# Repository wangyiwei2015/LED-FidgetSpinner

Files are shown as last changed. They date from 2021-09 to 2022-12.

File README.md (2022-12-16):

# LED-FidgetSpinner
Battery-powered LED Fidget Spinner. **PhOVS**

Design & concept reference: [8Mode Fidget Spinner](https://www.8mode.com/spinner/)

Warning: this is still under development.

Warning: there maybe better MCU model for this application.

### Development Tools

PCB: **KiCAD**

    --> ./FidgetSpinner-PCB/

Firmware: **STM32CubeMX** & **CLion**

    --> ./FidgetSpinner-FW/STM32L010_CLion/

3D Models: **Shapr3D** for iPad

    --> ./FidgetSpinner-Struct/

### BOM

| Name | Model | Package | Quantity | Price (CNY each) |
| --- | --- | --- | --- | --- |
| MCU | STM32L010K8T6 | | 1 | 33 |
| Regulator | BL8530 | | 1 | 0.16 |
| Optical Sensor | GP2S60 | | 1 | 3.50 |
| Switch | MSK-12C02 | | 1 | 0.16 |
| Button | | | 1 | |
| Battery | CR2450 | CR2450  | 3 | |
| Battery Case | | | 3 | |
| LED | warm-white | 0805 | 8 | |
| Diode | D | 0805 | 2 | 0.06 |
| L | 47uH | 0805 | 1 | |
| C | 100nF | 0805 | 3 | |
| C | 1uF | 0805 | 1 | |
| C | 47uF | 0805 | 1 | |
| R_LED | 1k1 | 0805 | 8 | |
| R_IR | 3k3 | 0805 | 1 | |
| R_Comp | 20k | 0805 | 1 | |
| R_Comp | 33k | 0805 | 1 | |
| R_Tr | 1M | 0805 | 1 | |
| R | 10k | 0805 | 3 | |

Different coin-sized 3V battery cells

| Name | Capacity(mAh) | I(uA) | Ic(mA) | Imax(mA) | Weight(g) |
| --- | --- | ----- | --- | --- | --- |
| CR2477 | 950 | 200 | 3 | 20 | 9.9 |
| CR2450 | 550 | 200 | 3 | 20 | 5.8 |
| CR2430 | 270 | 200 | 3 | 20 | 4.3 |
| CR3032 | 550 | 200 | 3 | 20 | 6.8 |
| CR2032 | 210 | 200 | 2 | 20 | 3.0 |
| CR2025 | 150 | 200 | 2 | 20 | 2.5 |

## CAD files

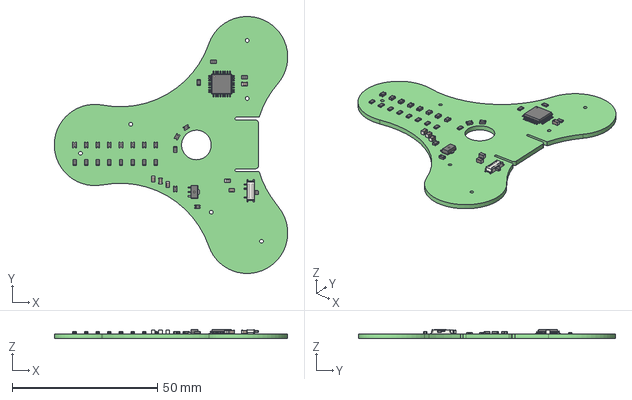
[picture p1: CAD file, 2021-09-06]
FidgetSpinner-PCB/FidgetSpinner.step
80.5 x 88.6 x 3.17 mm

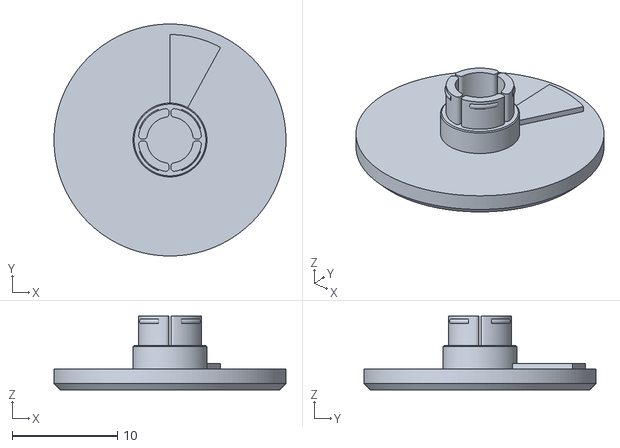
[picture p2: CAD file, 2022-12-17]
FidgetSpinner-Struct/PCap_v3.0-f.stl
22.0 x 22.0 x 7.00

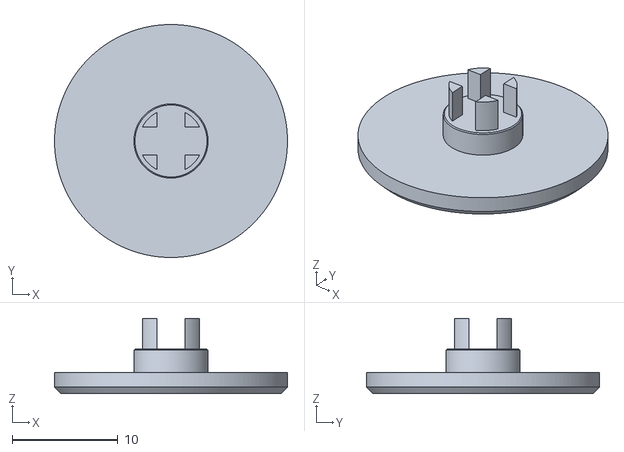
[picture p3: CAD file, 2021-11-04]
FidgetSpinner-Struct/PCap_v2.1.stl
22.0 x 22.0 x 7.10

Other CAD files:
FidgetSpinner-Struct/PCap_v3.0-b.stl

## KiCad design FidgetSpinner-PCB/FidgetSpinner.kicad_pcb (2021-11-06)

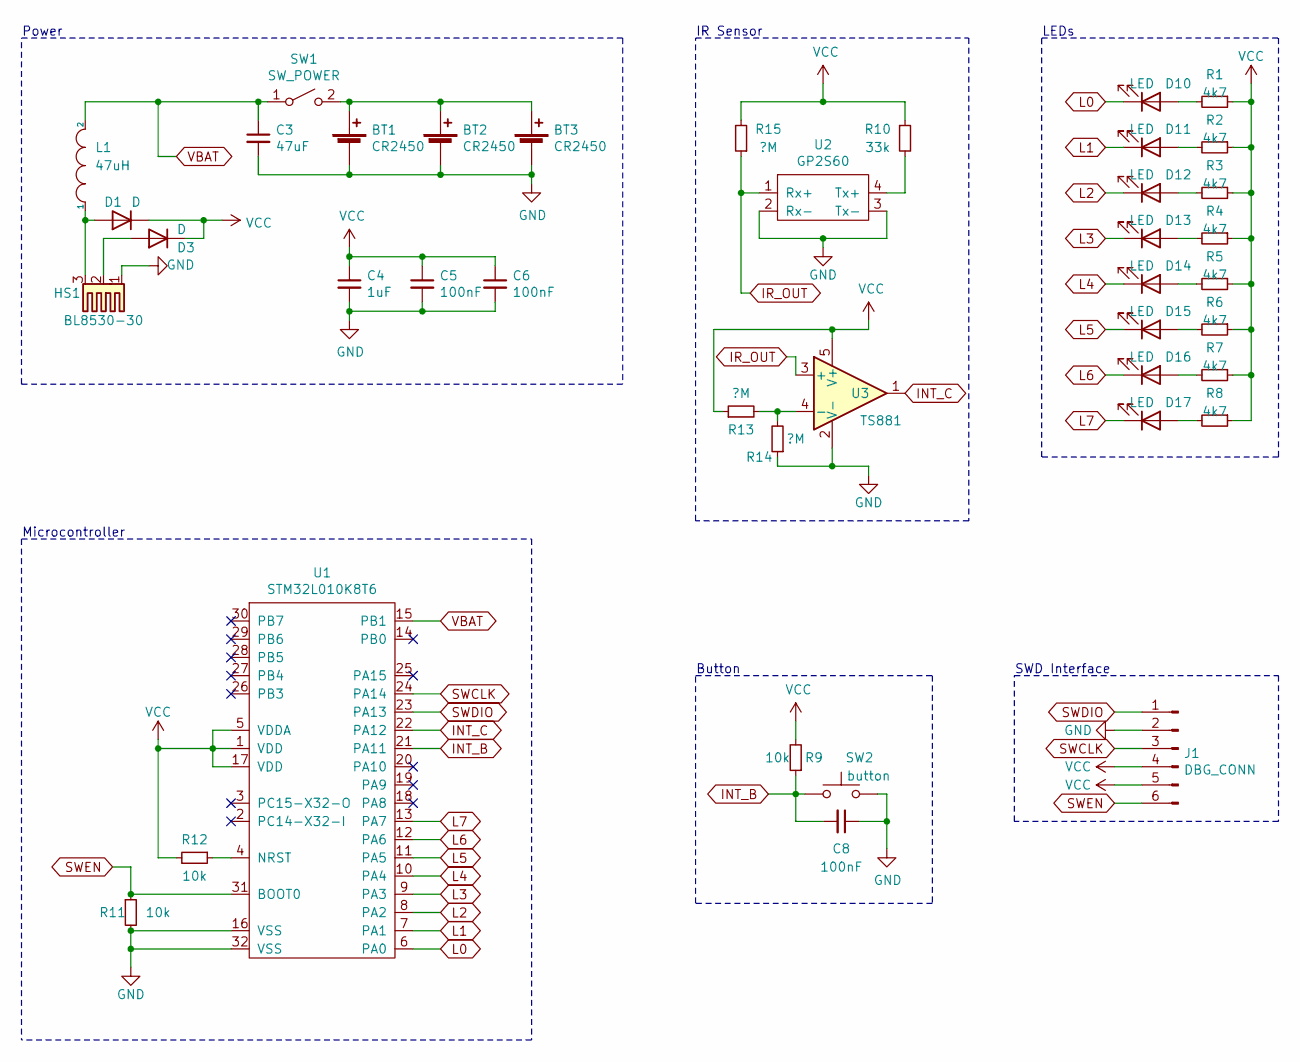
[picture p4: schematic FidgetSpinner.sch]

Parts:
BT1, BT2, BT3: CR2450; BatteryHolder_Keystone_3009_1x2450
C3: 47uF; C_0805_2012Metric_Pad1.18x1.45mm_HandSolder
C4: 1uF; C_0805_2012Metric_Pad1.18x1.45mm_HandSolder
C5, C6, C8: 100nF; C_0805_2012Metric_Pad1.18x1.45mm_HandSolder
D1, D3: D; D_0805_2012Metric_Pad1.15x1.40mm_HandSolder
D10, D11, D12, D13, D14, D15, D16, D17: LED; D_0805_2012Metric_Pad1.15x1.40mm_HandSolder
HS1: BL8530-30; SOT-89-3_Handsoldering
J1: DBG_CONN; PinHeader_1x06_P2.54mm_Horizontal
L1: 47uH; L_0805_2012Metric_Pad1.15x1.40mm_HandSolder
R1, R2, R3, R4, R5, R6, R7, R8: 4k7; R_0805_2012Metric_Pad1.20x1.40mm_HandSolder
R9, R11, R12: 10k; R_0805_2012Metric_Pad1.20x1.40mm_HandSolder
R10: 33k; R_0805_2012Metric_Pad1.20x1.40mm_HandSolder
R13, R14, R15: ?M; R_0805_2012Metric_Pad1.20x1.40mm_HandSolder
SW1: SW_POWER; SW_SPDT_PCM12
SW2: button; SW_SPST_SKQG_WithStem
U1: STM32L010K8T6; LQFP-32_7x7mm_P0.8mm
U2: GP2S60; GP2S60_3217
U3: TS881; SOT-353_SC-70-5

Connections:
GND: BT1.2 (-), BT2.2 (-), BT3.2 (-), C3.2, C4.2, C5.2, C6.2, C8.1, HS1.1, J1.2, R11.2, R14.1, SW2.2, U1.16 (VSS), U1.32 (VSS), U2.2 (Rx-), U2.3 (Tx-), U3.2 (V-); also elsewhere on the board
INT_B: C8.2, R9.1, SW2.1, U1.21 (PA11)
INT_C: U1.22 (PA12), U3.1; also elsewhere on the board
IR_OUT: R15.1, U2.1 (Rx+), U3.3 (+); also elsewhere on the board
L0: D10.1 (K), U1.6 (PA0)
L1: D11.1 (K), U1.7 (PA1)
L2: D12.1 (K), U1.8 (PA2)
L3: D13.1 (K), U1.9 (PA3)
L4: D14.1 (K), U1.10 (PA4)
L5: D15.1 (K), U1.11 (PA5)
L6: D16.1 (K), U1.12 (PA6)
L7: D17.1 (K), U1.13 (PA7)
unnamed: BT1.1 (+), BT2.1 (+), BT3.1 (+), SW1.2 (B)
unnamed: D1.2 (A), HS1.3, L1.1
unnamed: D3.2 (A), HS1.2
unnamed: D10.2 (A), R1.2
unnamed: D11.2 (A), R2.2
unnamed: D12.2 (A), R3.2
unnamed: D13.2 (A), R4.2
unnamed: D14.2 (A), R5.2
unnamed: D15.2 (A), R6.2
unnamed: D16.2 (A), R7.2
unnamed: D17.2 (A), R8.2
unnamed: R10.2, U2.4 (Tx+)
unnamed: R12.1, U1.4 (NRST)
unnamed 25: R13.2, R14.2, U3.4 (-); also elsewhere on the board
SWCLK: J1.3, U1.24 (PA14)
SWDIO: J1.1, U1.23 (PA13)
SWEN: J1.6, R11.1, U1.31 (BOOT0)
VBAT: C3.1, L1.2, SW1.1 (A), U1.15 (PB1)
VCC: C4.1, C5.1, C6.1, D1.1 (K), D3.1 (K), J1.4, J1.5, R1.1, R2.1, R3.1, R4.1, R5.1, R6.1, R7.1, R8.1, R9.2, R10.1, R12.2, R13.1, R15.2, U1.1 (VDD), U1.5 (VDDA), U1.17 (VDD), U3.5 (V+); also elsewhere on the board

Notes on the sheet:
Power
SWD Interface
Button
IR Sensor
LEDs
Microcontroller

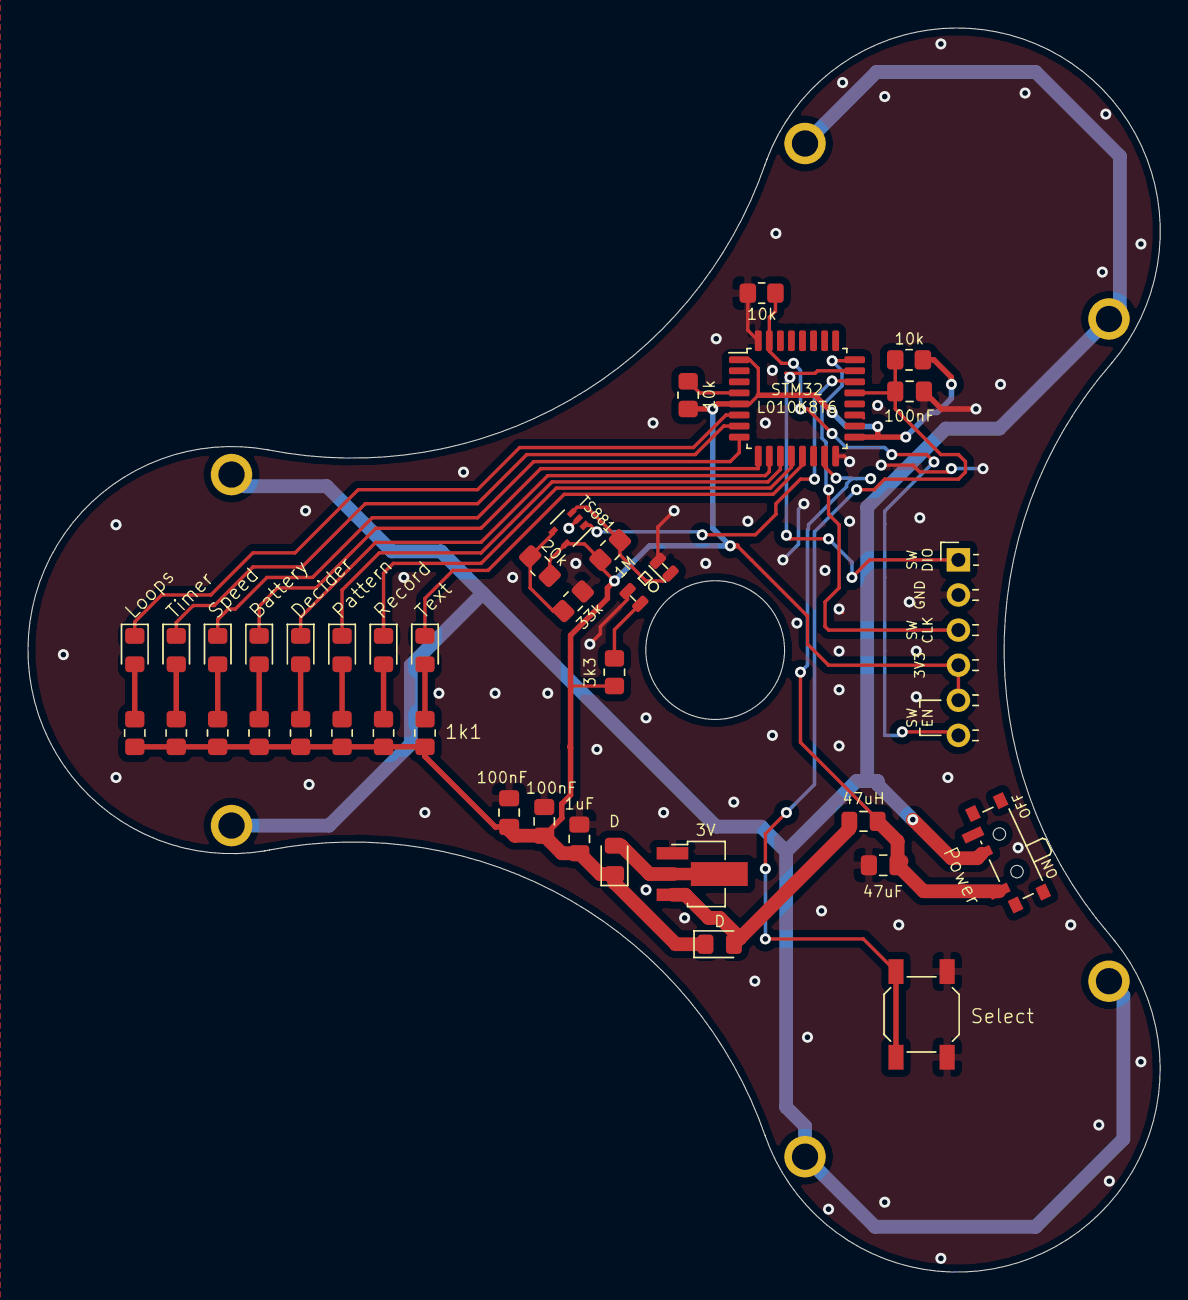
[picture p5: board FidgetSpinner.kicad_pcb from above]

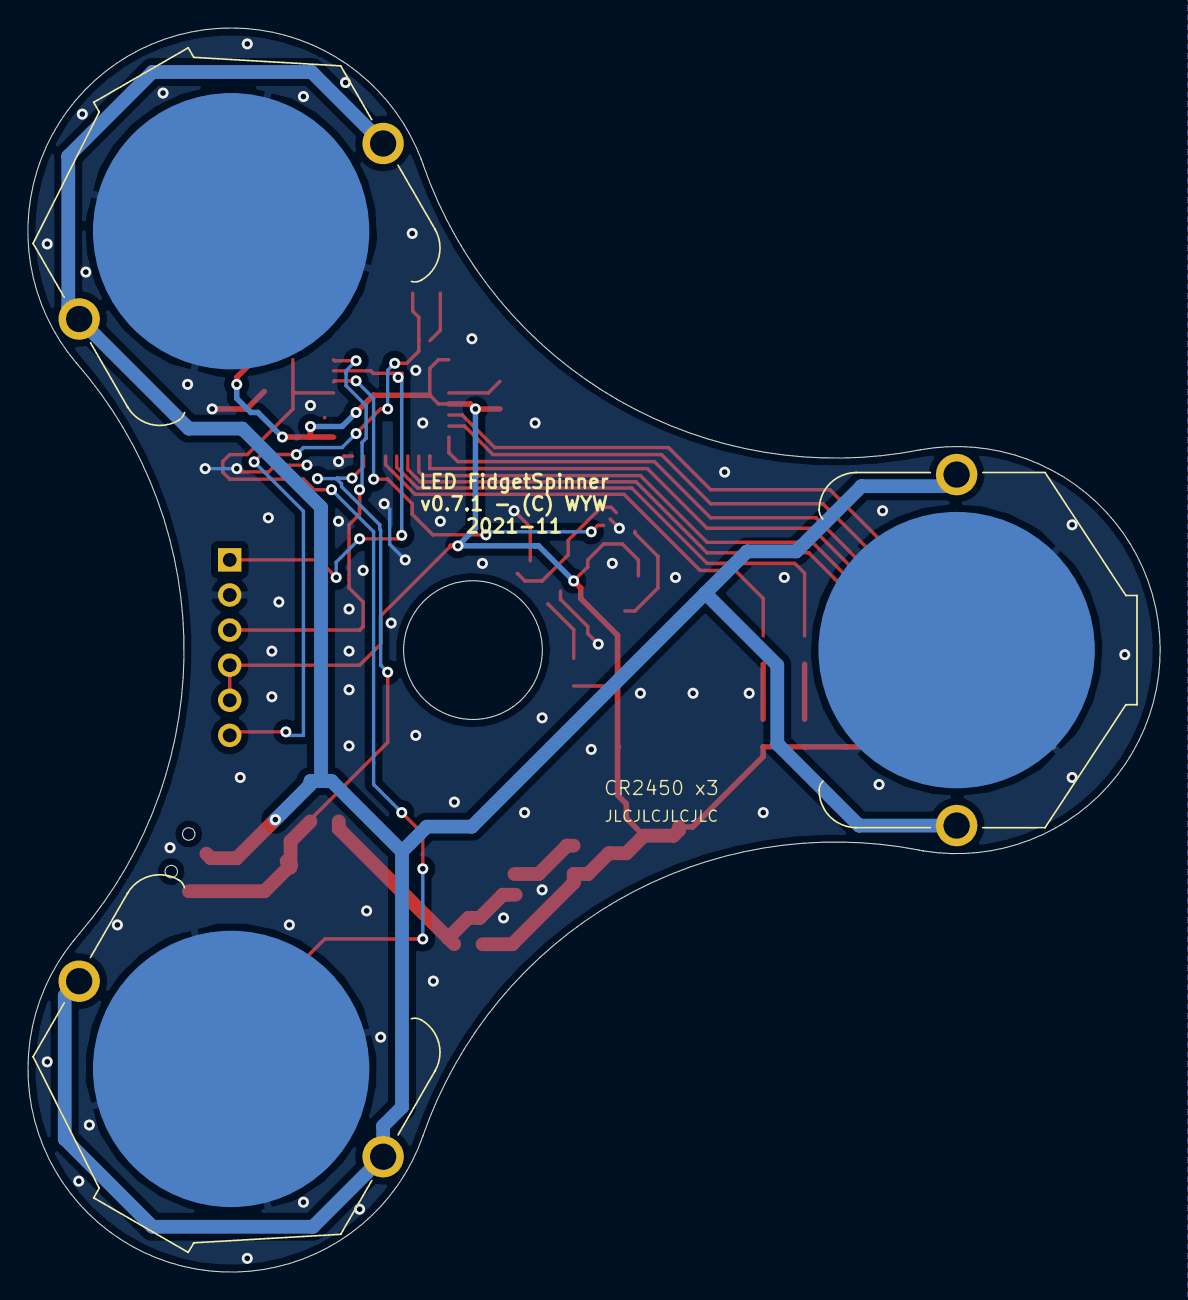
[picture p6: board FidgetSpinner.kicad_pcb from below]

Board: 2 copper layers, 81.9 x 90.0 mm, 41 parts (3 on the bottom side), 31 nets.

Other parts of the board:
TS881: TS881; SOT-353_SC-70-5

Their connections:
GND: TS881.2; also elsewhere on the board
INT_C: TS881.1; also elsewhere on the board
IR_OUT: TS881.3; also elsewhere on the board
unnamed 25: TS881.4; also elsewhere on the board
VCC: TS881.5; also elsewhere on the board

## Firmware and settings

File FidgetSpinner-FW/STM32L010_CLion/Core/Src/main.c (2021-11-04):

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
/* Includes ------------------------------------------------------------------*/
#include "main.h"

/* USER CODE BEGIN PD */
#define _STATE_STILL 1
#define _STATE_FIRSTROUND 2
#define _STATE_RUNNING 3
//Parameters
//#define _SPACE_LINE_INTERVAL 10
//#define _SPACE_CHAR_INTERVAL 100
#define _SPACE_LINE_SCALE 10
#define _SPACE_CHAR_SCALE 10
#define _ADC_TIMEOUT 50
//Debug |TODO: Comment out this def on production
// #define _DEBUG_MODE //----------------------------------------- DEBUG ------|
/* USER CODE END PD */

/* USER CODE BEGIN PM */
#define SET_LED(data) GPIOA->BSRR = (data & 0xff)|((~data & 0xff)<<16)
#define SHOW_MODE SET_LED(~(0b1 << mode))
uint8_t intt = 0;
void debug() {
    SET_LED(0);
    uint8_t i11 = 0;
    uint8_t i12 = 0;
    while(1) {
        i11 = HAL_GPIO_ReadPin(GPIOA, GPIO_PIN_11);
        i12 = HAL_GPIO_ReadPin(GPIOA, GPIO_PIN_12);
        SET_LED(0b11111111 - (i11 << 1) - (i12 << 6) - (intt));
        HAL_Delay(100);
    }
}
/* USER CODE END PM */

ADC_HandleTypeDef hadc;

/* USER CODE BEGIN PV */
static const uint8_t CHARS[53][5] = {
    {0b10000001,0b01101110,0b01110110,0b01111010,0b10000001},//0
    {0b01111111,0b01111101,0b00000000,0b01111111,0b01111111},//1
    {0b00111101,0b01011110,0b01101110,0b01110110,0b01111001},//2
    {0b10111101,0b01111110,0b01110110,0b01110110,0b10001001},//3
    {0b11001111,0b11010011,0b11011101,0b00000000,0b11011111},//4
    {0b10110000,0b01110110,0b01110110,0b01110110,0b10001110},//5
    {0b10000001,0b01110110,0b01110110,0b01110110,0b10001101},//6
    {0b11111100,0b11111110,0b00001110,0b11110010,0b11111100},//7
    {0b10001001,0b01110110,0b01110110,0b01110110,0b10001001},//8
    {0b10111001,0b01110110,0b01110110,0b01110110,0b10000001},//9
    {0b00000001,0b11110110,0b11110110,0b11110110,0b00000001},//10-A
    {0b00000000,0b01110110,0b01110110,0b01110110,0b10001001},//11-B
    {0b10000001,0b01111110,0b01111110,0b01111110,0b10111101},//12-C
    {0b00000000,0b01111110,0b01111110,0b10111101,0b11000011},//13-D
    {0b00000000,0b01110110,0b01110110,0b01110110,0b01111110},//14-E
    {0b00000000,0b11110110,0b11110110,0b11110110,0b11111110},//15-F
    {0b10000001,0b01111110,0b01110110,0b01110110,0b10000101},//16-G
    {0b00000000,0b11110111,0b11110111,0b11110111,0b00000000},//17-H
    {0b11111111,0b01111110,0b00000000,0b01111110,0b11111111},//18-I
    {0b11111110,0b01111110,0b01111110,0b10000000,0b11111110},//19-J
    {0b00000000,0b11110111,0b11101011,0b11011101,0b00111110},//20-K
    {0b00000000,0b01111111,0b01111111,0b01111111,0b01111111},//21-L
    {0b00000000,0b11111110,0b11000000,0b11111110,0b00000001},//22-M
    {0b00000000,0b11111110,0b10000001,0b01111111,0b00000000},//23-N
    {0b10000001,0b01111110,0b01111110,0b01111110,0b10000001},//24-O
    {0b00000000,0b11110110,0b11110110,0b11110110,0b11111001},//25-P
    {0b10000001,0b01111110,0b01011110,0b10111110,0b01000001},//26-Q
    {0b00000000,0b11110110,0b11100110,0b11010110,0b00111001},//27-R
    {0b10111001,0b01110110,0b01110110,0b01110110,0b10001101},//28-S
    {0b11111110,0b11111110,0b00000000,0b11111110,0b11111110},//29-T
    {0b10000000,0b01111111,0b01111111,0b01111111,0b10000000},//30-U
    {0b11100000,0b10011111,0b01111111,0b10011111,0b11100000},//31-V
    {0b10000000,0b01111111,0b10000111,0b01111111,0b10000000},//32-W
    {0b00011100,0b11101011,0b11110111,0b11101011,0b00011100},//33-X
    {0b11111100,0b11110011,0b00001111,0b11110011,0b11111100},//34-Y
    {0b00111110,0b01010110,0b01100110,0b01101010,0b01111100},//35-Z
    {0b11101111,0b11010111,0b10111011,0b01111101,0b11111111},//36 <
    {0b11111111,0b01111101,0b10111011,0b11010111,0b11101111},//37 >
    {0b11111111,0b11111111,0b01000000,0b11111111,0b11111111},//38 !
    {0b11111101,0b11111110,0b01001110,0b11110110,0b11111001},//39 ?
    {0b11111101,0b11111110,0b01001110,0b11110110,0b11111001},//40 ? |TODO
    {0b11110111,0b11110111,0b11110111,0b11110111,0b11110111},//41 -
    {0b01111111,0b01111111,0b01111111,0b01111111,0b01111111},//42 _
    {0b11110111,0b11110111,0b11000001,0b11110111,0b11110111},//43 +
    {0b11011011,0b11011011,0b11011011,0b11011011,0b11011011},//44 =
    {0b11111111,0b11111111,0b11011011,0b11111111,0b11111111},//45 :
    {0b10001111,0b01110001,0b01001110,0b10111110,0b01001101},//46 &
    {0b11011011,0b00000000,0b11011011,0b00000000,0b11011011},//47 #
    {0b10000001,0b01100110,0b01011010,0b01000110,0b11100001},//48 @
    {0b11000111,0b10000011,0b10000011,0b10000011,0b11000111},//49 cdot
    {0b10111011,0b11011111,0b11101111,0b11110111,0b10111011},//50 %
    {0b11011011,0b10110101,0b00000000,0b10101101,0b11011011},//51 $
    {0b11111111,0b11111111,0b11111111,0b11111111,0b11111111},//52 _spacer_
};

//Runtime - State
uint8_t mode = 0;
uint8_t state = _STATE_STILL;
uint8_t shouldHandleEXTI = 1;
uint8_t rnd;
//Runtime - SysTick
uint32_t prevTick = 0;
uint32_t loopTime = 0;
uint32_t spinStartTime = 0;
//Runtime - User
uint16_t speedRpm = 0;
uint16_t maxSpeedRpm = 0;
uint16_t loopCount = 0;
uint16_t maxLoopCount = 0;
uint8_t eepDataOffset = 0;
//Runtime - User - 2
uint8_t animationIndex = 0;
#define ANI_INDEX_MAX 5
/* USER CODE END PV */

void SystemClock_Config(void);
static void MX_GPIO_Init(void);
static void MX_ADC_Init(void);
/* USER CODE BEGIN 0 */
uint32_t loadEEPData() {
    const uint32_t saved = *(__IO uint32_t*)(DATA_EEPROM_BASE + 4 + eepDataOffset * 4);
    return saved;
}
//[31:16] max speed
//[15:00] max loops
void saveEEPData(uint32_t new) {
    shouldHandleEXTI = 0;
    HAL_DATA_EEPROMEx_Unlock();
    HAL_DATA_EEPROMEx_Program(
        FLASH_TYPEPROGRAMDATA_WORD,
        DATA_EEPROM_BASE + 4 + eepDataOffset * 4,
        new);
    shouldHandleEXTI = 1;
}

uint8_t readBatteryADC() {
    shouldHandleEXTI = 0;
    uint16_t adcResult = 0; //10-bit 1024
    HAL_ADC_Start(&hadc);
    HAL_ADC_PollForConversion(&hadc, _ADC_TIMEOUT);
    if(HAL_IS_BIT_SET(HAL_ADC_GetState(&hadc), HAL_ADC_STATE_REG_EOC))
        adcResult = HAL_ADC_GetValue(&hadc);
    else return 0;
    //adcResult * 3 / 1024 * 180 - 440
    double percentage = ((double)adcResult * 0.52734 - 440.0);
    if(percentage < 10) percentage = 1;
    shouldHandleEXTI = 1;
    return (uint8_t)percentage;
}

void showChar(const uint8_t id) {
    //for(unsigned character=0; character<sizeof(*str); ++character) {
    volatile uint32_t intervalScale = loopTime;
    //intervalScale /= 512;
    //uint32_t lineInterval = (intervalScale * (double)_SPACE_LINE_INTERVAL);
    uint32_t lineInterval = (intervalScale / _SPACE_LINE_SCALE);
    SET_LED(CHARS[id][0]);
    HAL_Delay(lineInterval);
    SET_LED(CHARS[id][1]);
    HAL_Delay(lineInterval);
    SET_LED(CHARS[id][2]);
    HAL_Delay(lineInterval);
    SET_LED(CHARS[id][3]);
    HAL_Delay(lineInterval);
    SET_LED(CHARS[id][4]);
    HAL_Delay(lineInterval);
    SET_LED(0b11111111);
    //HAL_Delay((intervalScale * (double)_SPACE_CHAR_INTERVAL)); //Char spacing width
    //HAL_Delay((intervalScale / _SPACE_CHAR_SCALE));
    HAL_Delay(lineInterval);
    HAL_Delay(lineInterval);
    HAL_Delay(lineInterval);
    HAL_Delay(lineInterval);
}
//example: str = [0,6,4,52,27,25,22] -> "064 RPM"

static inline void displayInMode(uint8_t _mode) {
    if(!shouldHandleEXTI) return;
    shouldHandleEXTI = 0;
    switch(_mode) {
        case 0: //0 - Loops counter
            showChar(49);
            showChar(52);
            if(loopCount >= 10000)
                showChar((uint8_t)(loopCount / 10000));
            if(loopCount >= 1000)
                showChar((uint8_t)((loopCount % 10000) / 1000));
            if(loopCount >= 100)
                showChar((uint8_t)((loopCount % 1000) / 100));
            if(loopCount >= 10)
                showChar((uint8_t)(loopCount / 10));
            showChar(loopCount % 10);
            break;
        case 1: //1 - Timer +mm:ss
            showChar(43); //+
            const uint32_t _spinTime = (prevTick - spinStartTime) / 1000;
            const uint8_t _sec = (uint8_t)(_spinTime % 60);
            const uint8_t _min = (uint8_t)(_spinTime / 60);
            showChar(_min / 10);
            showChar(_min % 10);
            showChar(45); //:
            showChar(_sec / 10);
            showChar(_sec % 10);
            break;
        case 2: //2 - RPM meter
            if(speedRpm >= 10000) {
                showChar(29); //T
                showChar(24); //O
                showChar(24); //O
                showChar(52); //_spacer_
                showChar(15); //F
                showChar(10); //A
                showChar(28); //S
                showChar(29); //T
            } else {
                if (speedRpm >= 1000)
                    showChar((uint8_t) (speedRpm / 1000));
                if (speedRpm >= 100)
                    showChar((uint8_t) ((speedRpm % 1000) / 100));
                if (speedRpm >= 10)
                    showChar((uint8_t) (speedRpm / 10));
                showChar(speedRpm % 10);
                showChar(52); //_spacer_
                showChar(27); //R
                showChar(25); //P
                showChar(22); //M
            }
            break;
        case 3: //3 - Battery
            __NOP();
            const uint8_t bat = readBatteryADC();
            if(bat > 99) { //100%
                showChar(1);
                showChar(0);
                showChar(0);
                showChar(50);
            } else if(bat > 9) { //2-Digit
                showChar(bat / 10);
                showChar(bat % 10);
                showChar(50);
            } else if(bat) { //LOW!
                showChar(21);
                showChar(24);
                showChar(32);
                showChar(38);
            } else { //ERROR
                showChar(14);
                showChar(27);
                showChar(27);
                showChar(24);
                showChar(27);
            }
            break;
        case 4: //4 - Random gen - yes / no / maybe
            if(prevTick - spinStartTime < 1280) {
                showChar(34); //Y
                showChar(14); //E
                showChar(28); //S
                showChar(52); //_SPACER_
                showChar(24); //O
                showChar(27); //R
                showChar(52); //_SPACER_
                showChar(23); //N
                showChar(24); //O
                showChar(52); //_SPACER_
                showChar(39); //?
            } else {
                if (rnd < 7) {
                    showChar(49); //_cdot_
                    showChar(34); //Y
                    showChar(14); //E
                    showChar(28); //S
                } else if (rnd < 14) {
                    showChar(49); //_cdot_
                    showChar(23); //N
                    showChar(24); //O
                } else {
                    showChar(49); //_cdot_
                    showChar(22); //M
                    showChar(10); //A
                    showChar(34); //Y
                    showChar(11); //B
                    showChar(14); //E
                }
            }
            break;
        case 5: //5 - Animation |TODO
            //
            break;
        case 7: //7 - User defined text |TODO
            showChar(0);
            showChar(1);
            showChar(2);
            showChar(3);
            showChar(4);
            showChar(5);
            showChar(6);
            showChar(7);
            break;
        case 6: //6 - Best score - max loops max time max speed
            showChar(11); //B
            showChar(14); //E
            showChar(28); //S
            showChar(29); //T
            showChar(45); //:
            if(((prevTick - spinStartTime) << 11) % 2) {
                if(maxLoopCount >= 10000)
                    showChar((uint8_t)(maxLoopCount / 10000));
                if(maxLoopCount >= 1000)
                    showChar((uint8_t)((maxLoopCount % 10000) / 1000));
                if(maxLoopCount >= 100)
                    showChar((uint8_t)((maxLoopCount % 1000) / 100));
                if(maxLoopCount >= 10)
                    showChar((uint8_t)(maxLoopCount / 10));
                showChar(maxLoopCount % 10);
                showChar(49); //_cdot_
            } else {
                if(maxSpeedRpm >= 1000)
                    showChar((uint8_t)((maxSpeedRpm % 10000) / 1000));
                if(maxSpeedRpm >= 100)
                    showChar((uint8_t)((maxSpeedRpm % 1000) / 100));
                if(maxSpeedRpm >= 10)
                    showChar((uint8_t)(maxSpeedRpm / 10));
                showChar(maxSpeedRpm % 10);
                showChar(52); //_spacer_
                showChar(27); //R
                showChar(25); //P
                showChar(22); //M
            }
            break;
        default: break;
    }
    shouldHandleEXTI = 1;
}

void HAL_GPIO_EXTI_Callback(uint16_t GPIO_Pin) {
#ifdef _DEBUG_MODE
    if(GPIO_Pin == GPIO_PIN_12) {
        intt = ~intt;
    }
    return;
#endif
    if(!shouldHandleEXTI) return;
    if(GPIO_Pin == GPIO_PIN_11) { //Button
        if(state == _STATE_STILL) {
            ++mode;
            if(mode > 7) mode = 0;
            SHOW_MODE;
        }
    } else if(GPIO_Pin == GPIO_PIN_12) { //Sensor
        const uint32_t tick = HAL_GetTick();
        switch(state) {
            case _STATE_STILL:
                SET_LED(0xff);
                state = _STATE_FIRSTROUND;
                prevTick = tick;
                break;
            case _STATE_FIRSTROUND:
                state = _STATE_RUNNING;
                loopTime = tick - prevTick;
                prevTick = tick;
                spinStartTime = tick;
                loopCount = 1;
                rnd = prevTick % 16;
                break;
            case _STATE_RUNNING:
                prevTick = tick;
                //loopTime in ms
                //loopTime = (loopTime >> 2) + ((tick - prevTick) >> 2) * 3;
                loopTime = tick - prevTick;
                ++loopCount;
                speedRpm = 60000 / loopTime;
                displayInMode(mode);
                break;
            default:
                break;
        }
    }
}

//void SysTick_Handler() {
    //
//}
/* USER CODE END 0 */

/**
  * @brief  The application entry point.
  * @retval int
  */
int main(void)
{
  /* MCU Configuration--------------------------------------------------------*/

  /* Reset of all peripherals, Initializes the Flash interface and the Systick. */
  HAL_Init();

  /* Configure the system clock */
  SystemClock_Config();

  /* USER CODE BEGIN SysInit */
#ifndef _DEBUG_MODE
    uint8_t savedOffset = *(__IO uint8_t*)(DATA_EEPROM_BASE);
    eepDataOffset = savedOffset;
    uint32_t savedData = 0;
    savedData = loadEEPData();
    maxSpeedRpm = savedData >> 16;
    maxLoopCount = savedData % (1 << 16);
#endif
  /* USER CODE END SysInit */

  /* Initialize all configured peripherals */
  MX_GPIO_Init();
  MX_ADC_Init();
  /* USER CODE BEGIN 2 */
#ifdef _DEBUG_MODE
    debug();
#else
    SHOW_MODE;
#endif
  /* USER CODE END 2 */

  /* Infinite loop */
  /* USER CODE BEGIN WHILE */

  while(1) {
      if(state != _STATE_STILL) {
          //Timeout watchdog
          if(HAL_GetTick() - prevTick > 1024) {
              state = _STATE_STILL;
              SHOW_MODE;
              if(speedRpm > maxSpeedRpm || loopCount > maxLoopCount) {
                  maxSpeedRpm = speedRpm;
                  maxLoopCount = loopCount;
                  saveEEPData((((uint32_t)maxSpeedRpm) << 16) + maxLoopCount);
              }
              ++animationIndex;
              if(animationIndex >= ANI_INDEX_MAX) animationIndex = 0;
          }
      }
    /* USER CODE END WHILE */

    /* USER CODE BEGIN 3 */
  }
  /* USER CODE END 3 */
}

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


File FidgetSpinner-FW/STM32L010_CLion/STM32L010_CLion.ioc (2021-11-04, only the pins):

Mcu.UserName=STM32L010K8Tx
PA0.Signal=GPIO_Output
PA1.Signal=GPIO_Output
PA10.Signal=GPIO_Analog
PA11.Signal=GPXTI11
PA12.Signal=GPXTI12
PA13.Signal=GPIO_Analog
PA14.Signal=GPIO_Analog
PA15.Signal=GPIO_Analog
PA2.Signal=GPIO_Output
PA3.Signal=GPIO_Output
PA4.Signal=GPIO_Output
PA5.Signal=GPIO_Output
PA6.Signal=GPIO_Output
PA7.Signal=GPIO_Output
PA8.Signal=GPIO_Analog
PA9.Signal=GPIO_Analog
PB0.Signal=GPIO_Analog
PB1.Signal=ADC_IN9
PB3.Signal=GPIO_Analog
PB4.Signal=GPIO_Analog
PB5.Signal=GPIO_Analog
PB6.Signal=GPIO_Analog
PB7.Signal=GPIO_Analog
PC14-OSC32_IN.Signal=GPIO_Analog
PC15-OSC32_OUT.Signal=GPIO_Analog

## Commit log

2021-08-30 init pcb v0.1.0
    [FidgetSpinner-B_Cu.gbr, FidgetSpinner-B_Mask.gbr, FidgetSpinner-B_Paste.gbr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]
2021-08-30 fixed: CR2477 label
    [FidgetSpinner.kicad_pcb]
2021-09-03 changed to STM32L0 MCU
    [FidgetSpinner.sch]
2021-09-04 changed to STM32 and CR2450
    [FidgetSpinner-B_Cu.gbr, FidgetSpinner-B_Mask.gbr, FidgetSpinner-B_Paste.gbr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]
2021-09-04 added eSWD dbg board
    [SWD_5pin.kicad_pcb, SWD_5pin.sch]
2021-09-06 button animations
    [FidgetSpinner.kicad_pcb, FidgetSpinner.sch, FidgetSpinner.step]
2021-09-12 fixed holes and gnd
    [FidgetSpinner.kicad_pcb]
2021-09-16 backup of CLion project
    [FidgetSpinner.kicad_pcb, FidgetSpinner.sch]
2021-09-17 updated edge conn
    [FidgetSpinner.kicad_pcb]
2021-09-17 added ADC feature
2021-09-17 added battery to ADC connection for PCB
    [FidgetSpinner.kicad_pcb, FidgetSpinner.sch]
2021-09-17 regenerated codes and project files
    due to a strange error
    [stm32l0discovery.cfg, stm32ldiscovery.cfg]
2021-09-19 added features
    [FidgetSpinner.kicad_pcb]
2021-09-19 optimized codes and added ADC config MX
2021-09-20 using GP2S27 optic sensor
    [FidgetSpinner.sch]
2021-09-20 updated PCB
    [FidgetSpinner.kicad_pcb]
2021-09-22 tested and fixed: ADC and EEPROM
    [FidgetSpinner.kicad_pcb]
2021-09-27 important updates
    [FidgetSpinner.kicad_pcb, FidgetSpinner.sch]
2021-09-27 removed edge connector
    [FidgetSpinner.kicad_pcb, FidgetSpinner.sch]
2021-09-27 optimized labels
    [FidgetSpinner.kicad_pcb]
2021-10-10 added GP2S60 test board
    [FidgetSpinner-GP2S60_Tester.kicad_pcb, FidgetSpinner-GP2S60_Tester.sch]
2021-10-15 bug fixes
    [FidgetSpinner.kicad_pcb, FidgetSpinner.sch]
2021-11-04 resistor value & firmware updates
    [FidgetSpinner.kicad_pcb]
2021-11-06 rearranged files
    [FidgetSpinner-GP2S60_Tester.kicad_pcb, FidgetSpinner-GP2S60_Tester.sch, FidgetSpinner.kicad_pcb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]
2022-12-17 updated caps
    [PCap_v3.0-b.stl, PCap_v3.0-f.stl]

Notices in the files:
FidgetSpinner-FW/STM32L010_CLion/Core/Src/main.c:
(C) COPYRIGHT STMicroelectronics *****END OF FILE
